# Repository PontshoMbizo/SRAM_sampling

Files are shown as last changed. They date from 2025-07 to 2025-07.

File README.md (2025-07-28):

# 🧠 MAX10 SRAM Data Capture Interface

A Verilog-based system for **non-invasively reading data** from a legacy **SRAM chip (M48T35)** used in submarine control systems, then sending that data over **I²C** to an external device. Built on the **MAX10 (DE10-Lite) FPGA** platform.

## 🚧 Problem Overview

A control system on a submarine loads boot and configuration data from a non-volatile SRAM (M48T35). The SRAM is battery-backed — if the internal battery dies, all critical data is lost.

The SRAM only makes valid data available for **~10 ns**, approximately **70 ns after** the `E_n` (Chip Enable) and `G_n` (Output Enable) signals are asserted. Data must be captured within this narrow window

## 🎯 Goal

- ✅ Monitor SRAM control lines (`E_n`, `G_n`) in real time
- ✅ Precisely capture data + address during the valid 10 ns window
- ✅ Avoid loading or interfering with the SRAM or its ASIC controller

## ⚙️ System Architecture

### 🔩 High-Level Design

| Component | Role |
|---|---|
| **PLL Block** | Generates a 200MHz clock from 50MHz input 	|
| **Counter Module**| Produces a 5ns-resolution counter to time the 70ns delay				|
| **FSM** | Monitors `E_n` and `G_n`, triggers capture at precise timing |
| **Register Bank** | Captures 8-bit `DATA` and 15-bit `ADDR` lines |

## 🛠️ Hardware Interface

- **SRAM operates at 5V** logic; DE10-Lite GPIOs are 3.3V-tolerant.
- I used **8-bit bus buffers** to safely interface the FPGA with the SRAM, preventing reverse current or contention.

---

## 🔬 Simulations

Simulation files are provided under `firmware/simulations/src`. They verify:

- Correct timing delay and edge detection
- Successful data/address latching at 70ns

Use **ModelSim** or **QuestaSim** to run the testbenches.

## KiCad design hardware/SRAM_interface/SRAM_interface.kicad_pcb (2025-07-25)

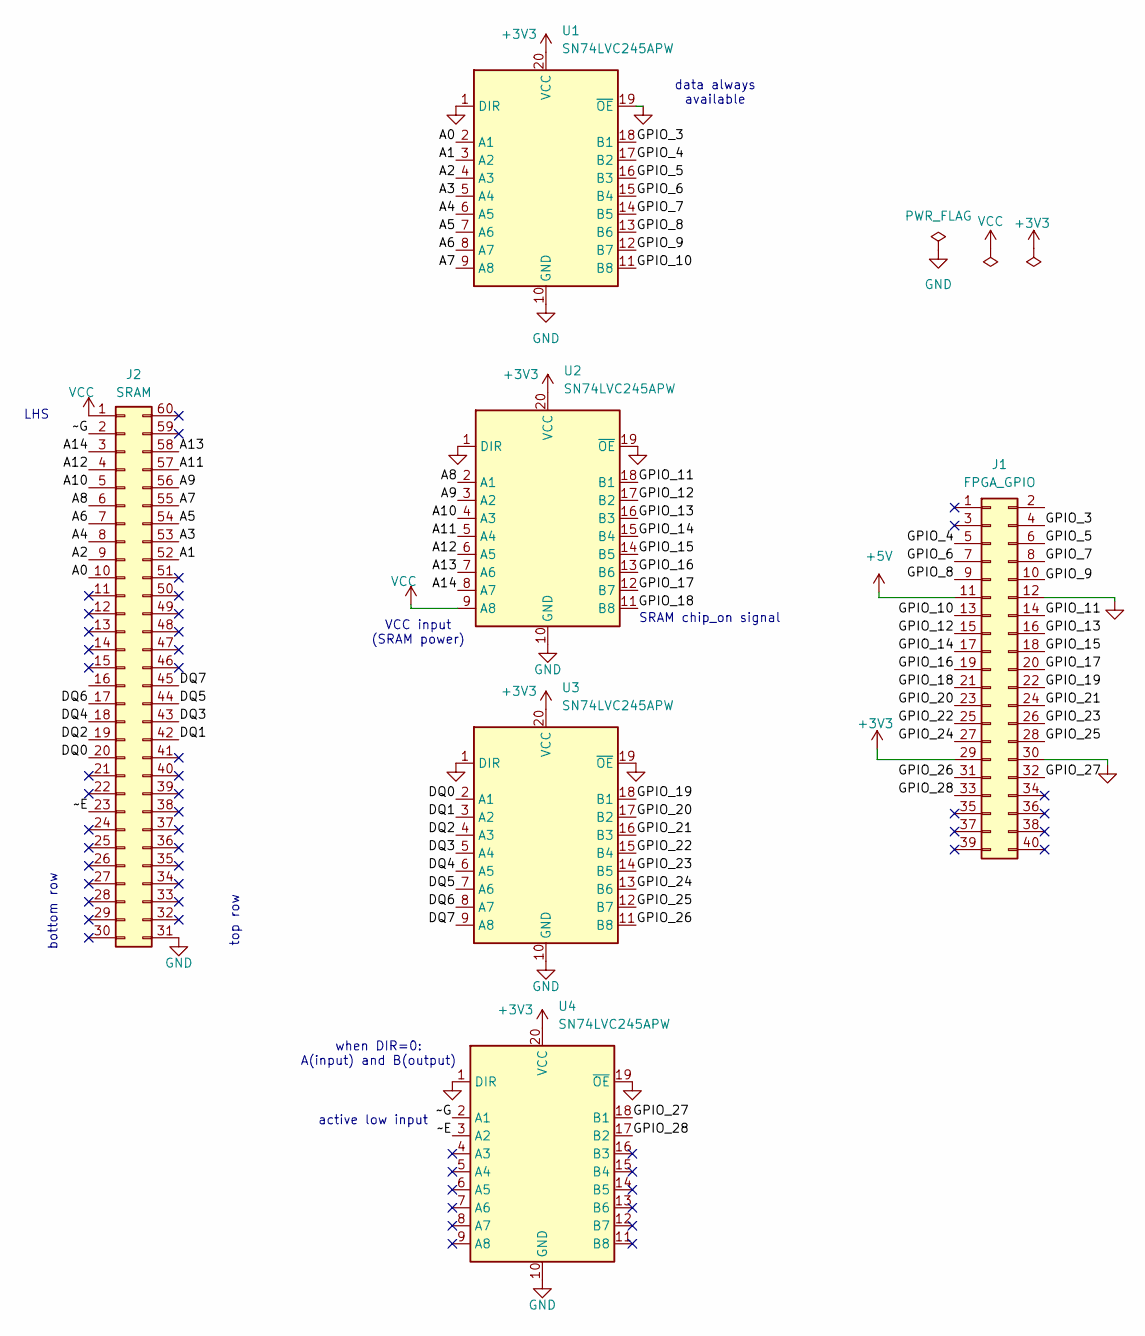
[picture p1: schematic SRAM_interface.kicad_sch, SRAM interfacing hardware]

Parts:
J1: FPGA_GPIO; IDC-Header_2x20_P2.54mm_Vertical
J2: SRAM; IDC-Header_2x30_P2.54mm_Vertical
U1, U2, U3, U4: SN74LVC245APW; TSSOP-20_4.4x6.5mm_P0.65mm

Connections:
+3V3: J1.29, U1.20 (VCC), U2.20 (VCC), U3.20 (VCC), U4.20 (VCC)
+5V: J1.11
/A0: J2.10, U1.2 (A1)
/A1: J2.52, U1.3 (A2)
/A2: J2.9, U1.4 (A3)
/A3: J2.53, U1.5 (A4)
/A4: J2.8, U1.6 (A5)
/A5: J2.54, U1.7 (A6)
/A6: J2.7, U1.8 (A7)
/A7: J2.55, U1.9 (A8)
/A8: J2.6, U2.2 (A1)
/A9: J2.56, U2.3 (A2)
/A10: J2.5, U2.4 (A3)
/A11: J2.57, U2.5 (A4)
/A12: J2.4, U2.6 (A5)
/A13: J2.58, U2.7 (A6)
/A14: J2.3, U2.8 (A7)
/DQ0: J2.20, U3.2 (A1)
/DQ1: J2.42, U3.3 (A2)
/DQ2: J2.19, U3.4 (A3)
/DQ3: J2.43, U3.5 (A4)
/DQ4: J2.18, U3.6 (A5)
/DQ5: J2.44, U3.7 (A6)
/DQ6: J2.17, U3.8 (A7)
/DQ7: J2.45, U3.9 (A8)
/GPIO_3: J1.4, U1.18 (B1)
/GPIO_4: J1.5, U1.17 (B2)
/GPIO_5: J1.6, U1.16 (B3)
/GPIO_6: J1.7, U1.15 (B4)
/GPIO_7: J1.8, U1.14 (B5)
/GPIO_8: J1.9, U1.13 (B6)
/GPIO_9: U1.12 (B7)
/GPIO_10: J1.13, U1.11 (B8)
/GPIO_11: J1.14, U2.18 (B1)
/GPIO_12: J1.15, U2.17 (B2)
/GPIO_13: J1.16, U2.16 (B3)
/GPIO_14: J1.17, U2.15 (B4)
/GPIO_15: J1.18, U2.14 (B5)
/GPIO_16: J1.19, U2.13 (B6)
/GPIO_17: J1.20, U2.12 (B7)
/GPIO_18: J1.21, U2.11 (B8)
/GPIO_19: J1.22, U3.18 (B1)
/GPIO_20: J1.23, U3.17 (B2)
/GPIO_21: J1.24, U3.16 (B3)
/GPIO_22: J1.25, U3.15 (B4)
/GPIO_23: J1.26, U3.14 (B5)
/GPIO_24: J1.27, U3.13 (B6)
/GPIO_25: J1.28, U3.12 (B7)
/GPIO_26: J1.31, U3.11 (B8)
/GPIO_27: J1.32, U4.18 (B1)
/GPIO_28: J1.33, U4.17 (B2)
/~E: J2.23, U4.3 (A2)
/~G: J2.2, U4.2 (A1)
GND: J1.12, J1.30, J2.31, U1.1 (DIR), U1.10 (GND), U1.19 (~OE), U2.1 (DIR), U2.10 (GND), U2.19 (~OE), U3.1 (DIR), U3.10 (GND), U3.19 (~OE), U4.1 (DIR), U4.10 (GND), U4.19 (~OE)
VCC: J2.1, U2.9 (A8)

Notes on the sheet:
when DIR=0: A(input) and B(output)
VCC input (SRAM power)
bottom row
top row
LHS
SRAM chip_on signal
active low input
data always available

Board: 2 copper layers, 6 parts (0 on the bottom side), 53 nets, no tracks yet.

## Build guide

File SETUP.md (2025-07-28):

# Setting up the DE10-Lite FPGA DevBoard

#### Downloading MAX10 specific tools

- make a [terasic](https://www.terasic.com.tw/en/) account 
- download the [CD-ROM](https://download.terasic.com/downloads/cd-rom/de10-lite/)
- the CD-ROM contains schematics and datasheets of components on the DevBoard
#### Installing Intel Quartus Prime Lite Edition

- [Intel Quartus Prime Lite Edition Downloads](https://www.intel.com/content/www/us/en/software/programmable/quartus-prime/download.html)
- Choose the **Lite Edition**, which supports the **MAX 10 FPGA** on the DE10-Lite.
- on installation, select:
  - **Quartus Lite Software**
  - **MAX 10 device support files**
  - and install in default location: (`C:\intelFPGA_lite\XX.X\`) where `XX.X` is the version you downloaded
#### Installing the USB-Blaster driver

The next step is to install the USB driver; The **DE10-Lite** uses a **USB-Blaster** to program the FPGA via USB.

- Plug in the DE10-Lite board
- open the device manager; you should see “Unknown Device” or “USB-Blaster”
- to install the driver:
	1. Right-click > **Update Driver**
	2. Choose **Browse my computer for drivers**
	3. Navigate to: `C:\intelFPGA_lite\XX.X\quartus\drivers\usb-blaster`
	4. Select the folder and and click install.
#### Selecting the Hardware

- Open **Quartus Prime Lite**
- Go to **Tools > Programmer**
- Select **USB-Blaster**  under hardware setup.
#### Starting a Project

Intel does a better Job explaining this part 😅
[here's the link](https://www.intel.com/content/www/us/en/developer/articles/training/program-fpga-device/terasic.html) 
just keep in mind, the device is: **10M50DAF484C7G**, **MAX 10** family, **MAX10 DE** version

## The Methods used:

[PLL](https://www.intel.com/content/www/us/en/docs/programmable/683732/17-0/altpll-phase-locked-loop-ip-core-user-guide.html)

[timer](https://www.geeksforgeeks.org/digital-logic/counter-design-using-verilog-hdl/)

[buffering circuits](https://www.ti.com/lit/ds/symlink/sn74cb3t3245.pdf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)

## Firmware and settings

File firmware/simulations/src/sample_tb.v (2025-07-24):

`timescale 1ns / 1ps

module sample_tb;

    // DUT Inputs
    reg MAX10_CLK1_50 = 0;
    reg clk_200 = 0;
    
    reg [35:0] GPIO_in = 36'b0;       // input GPIO signals
    wire [35:0] GPIO;                 // connects to DUT
    assign GPIO = GPIO_in;

    //simulation outputs
    //wire [12:0] DRAM_ADDR;
    //wire [1:0]  DRAM_BA;
    //wire        DRAM_CAS_N, DRAM_CKE, DRAM_CLK, DRAM_CS_N;
    //wire [15:0] DRAM_DQ;
    //wire        DRAM_LDQM, DRAM_RAS_N, DRAM_UDQM, DRAM_WE_N;
    //DRAM signals are not used in this simulation
    // but can be added later if needed

    wire LEDR0; //debug output 
    wire E = GPIO[0];
    wire O = GPIO[1];
    wire [14:0] input_address = GPIO[15:2];  // GPIO[2] to GPIO[15]
    wire [7:0]  input_data    = GPIO[23:16]; // GPIO[16] to GPIO[23]
    wire [14:0] output_ADDR;
    wire [7:0]  output_DATA;
    wire read_signal;
    wire [3:0] count_output;

    // Instantiate DUT
    sample dut (
        .MAX10_CLK1_50(MAX10_CLK1_50),
        .clk_200(clk_200),
        //.DRAM_ADDR(DRAM_ADDR), will use later to save the captured data into
        //.DRAM_BA(DRAM_BA),
        //.DRAM_CAS_N(DRAM_CAS_N),
        //.DRAM_CKE(DRAM_CKE),
        //.DRAM_CLK(DRAM_CLK),
        //.DRAM_CS_N(DRAM_CS_N),
        //.DRAM_DQ(DRAM_DQ),
        //.DRAM_LDQM(DRAM_LDQM),
        //.DRAM_RAS_N(DRAM_RAS_N),
        //.DRAM_UDQM(DRAM_UDQM),
        //.DRAM_WE_N(DRAM_WE_N),
        .GPIO(GPIO),
        .LEDR0(LEDR0),
        .output_DATA(output_DATA),
        .output_ADDR(output_ADDR),
        .read_signal(read_signal),
        .count_output(count_output)
    );

    // Clock generation
    always #10 MAX10_CLK1_50 = ~MAX10_CLK1_50; // 50 MHz
    always #2.5 clk_200 = ~clk_200; //the clk_200 in simulations...

    // Test procedure
    initial begin
        $display("Starting simulation...");
        $dumpfile("sample_tb.vcd");
        $dumpvars(0, clk_200);
        $dumpvars(0, dut);  

        // Set GPIO[0]=0 (E active), GPIO[1]=0 (O active)
        GPIO_in[0] = 0;
        GPIO_in[1] = 0;

        // Providing valid address and data
        GPIO_in[15:2]  = 14'b10101010101010;  // address
        GPIO_in[23:16] = 8'hAB;     // data

        #100 //hold for a couple of cycles

        // Simulating different states of E (GPIO[0]) and O(GPIO[1])

        //|E|O|
        //-----
        //|0|0|
        //|0|1|
        //|1|0|
        //|1|1|
        //-----

        GPIO_in[0] = 0;
        GPIO_in[1] = 0; #80;

        GPIO_in[0] = 0;
        GPIO_in[1] = 1; #80;

        GPIO_in[0] = 1;
        GPIO_in[1] = 0; #80;

        GPIO_in[0] = 1;
        GPIO_in[1] = 1; #80;

        // Providing new data
        GPIO_in[15:2]  = 14'd5678;
        GPIO_in[23:16] = 8'hCD;

        #20;

        // Change E/O again

        GPIO_in[0] = 0;
        GPIO_in[1] = 0; #80;

        GPIO_in[0] = 0;
        GPIO_in[1] = 1; #80;

        GPIO_in[0] = 1;
        GPIO_in[1] = 0; #80;

        GPIO_in[0] = 1;
        GPIO_in[1] = 1; #80;

        #100;
        $display("Simulation done.");
        $stop;
    end
endmodule

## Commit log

2025-07-24 working simulations and included hardware_interface schematic
    [SRAM_interface.kicad_pcb, SRAM_interface.kicad_sch]
2025-07-25 pin mapping complete, imported to PCB Editor
    [SRAM_interface.kicad_pcb, SRAM_interface.kicad_sch]
2025-07-28 final commit?
    [SRAM_interface.kicad_sch]
